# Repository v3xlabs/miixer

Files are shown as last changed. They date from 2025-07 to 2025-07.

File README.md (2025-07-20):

<p align="center">
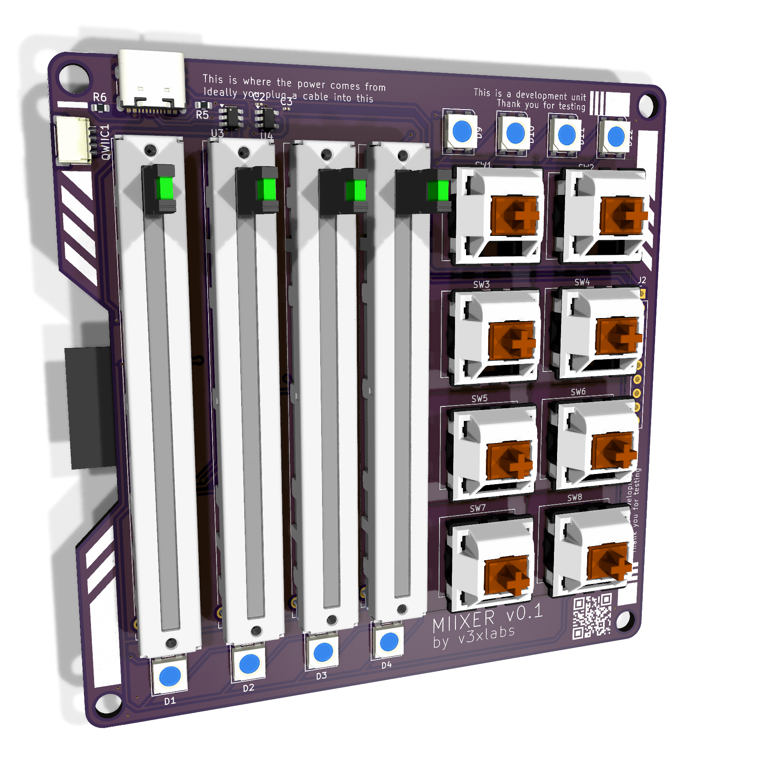
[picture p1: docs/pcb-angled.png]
MIIXER
  
</p>

# MIIXER

An open-hardware midi controller with esp32-c3, 4 linear faders, 8 keyswitches.

> [!NOTE]
> This is a work in progress.

## Technical Specs

- **Processor**: esp32-s3
- **Inputs**
  - 4 linear potentiometers 600mm
  - 8 Cherry MX Switches
- **ICs**
  - [PCF8574T](https://jlcpcb.com/api/file/downloadByFileSystemAccessId/8624297452529963008) - I2C IO Expander
  - [ADS1115IDGS](https://jlcpcb.com/api/file/downloadByFileSystemAccessId/8624297452529963008) - I2C ADC Expander
  - [AP2127K-3.3](https://www.diodes.com/assets/Datasheets/AP2127.pdf) - 5v to 3.3v LDO
  - [USBLC6-2SC6](https://www.st.com/resource/en/datasheet/usblc6-2.pdf) - ESD Protection
- **Connectivity**:
  - USB-C (Power, Data & Flash)
  - Wifi & BLE

## Photos

See the [docs](docs) folder for the rendered schematics, PCBs, and 3D renders.

<p align="center">
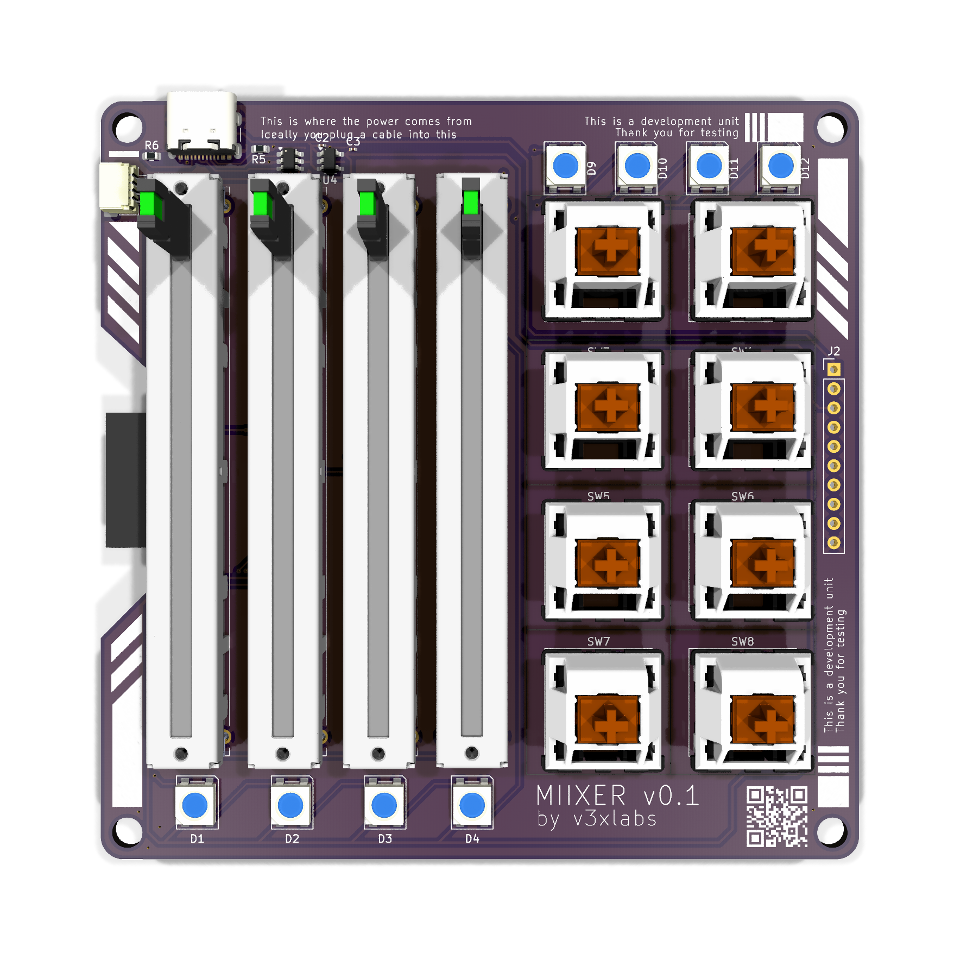
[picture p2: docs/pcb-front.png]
Front of MIIXER
  
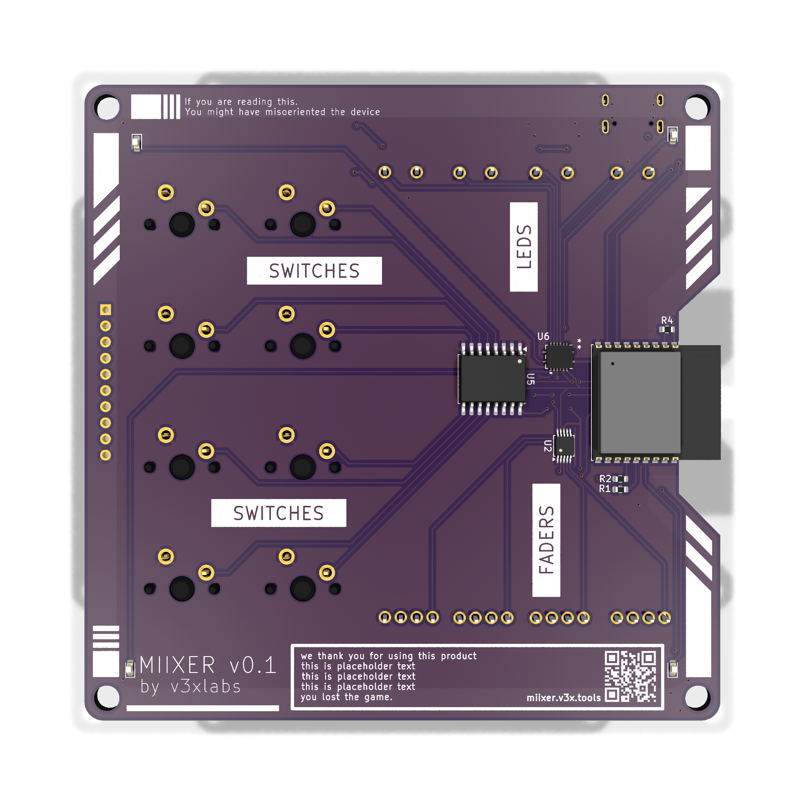
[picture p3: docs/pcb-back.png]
Back of MIIXER
  
</p>

## ESPHome Compatability

Due to the fact that this devices uses common off-the-shelf I2C ICs and is esp32-c3 based, you can easily use it with ESPHome.

```yaml
# TODO: This yaml file is work in progress, its ment to give an impression, its has not been confirmed functional.
i2c:
  sda: GPIO8
  scl: GPIO9
  scan: true

# 4x Fader Input
ads1115:
  address: 0x48 # todo confirm
  update_interval: 5s
  # todo interrupt pin (io6)

# 4x Fader LEDs
tcl59208f:
  id: led_drv # optional
  address: # todo

# 8x Keyswitch Input
pcf8574:
  id: expander # optional
  address: 0x20 # todo confirm
  # todo interrupt pin (io7)

binary_sensor:
  # 8x Keyswitch Input
  - platform: pcf8574
    pin: P0
    name: "Switch 1"
    # todo add 7 more pins

sensor:
  # 4x Fader Analog Input
  - platform: ads1115
    multiplexer: 'A0_GND' # todo
    gain: 6.144 # todo
    # todo 3 more pins

output:
  # 4x Fader LEDs
  - platform: tcl59208f
    driver: led_drv # optional
    id: led1
    channel: 0
  - platform: tcl59208f
    driver: led_drv # optional
    id: led2
    channel: 1
  - platform: tcl59208f
    driver: led_drv # optional
    id: led3
    channel: 2
  - platform: tcl59208f
    driver: led_drv # optional
    id: led4
    channel: 3

light:
  # 4x Fader SK6812
  - platform: fastled_clockless
    chipset: SK6812
    pin: GPIO3
    num_leds: 4
    rgb_order: GRB
    name: "SK6812 Array"
```

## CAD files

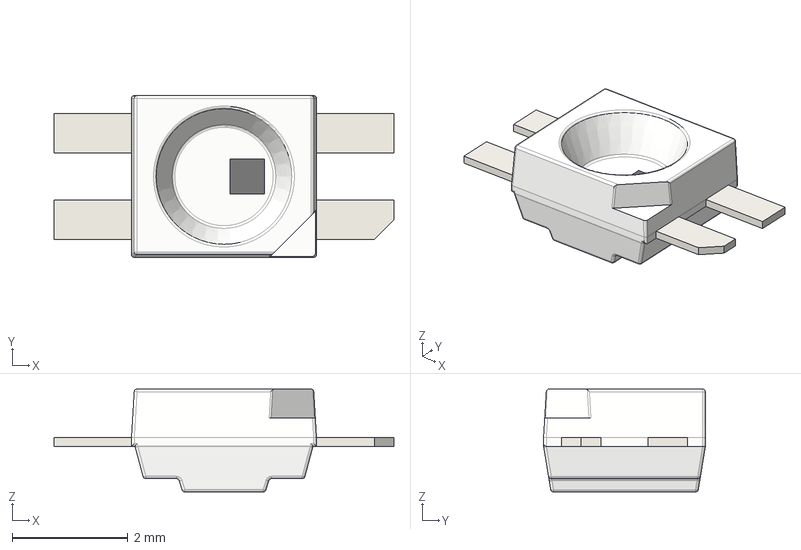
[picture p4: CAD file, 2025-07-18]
footprints/cad_models/sk6812mini-e-1.snapshot.3/LED_SK6812MINI-E.step
5.88 x 2.80 x 1.78 mm

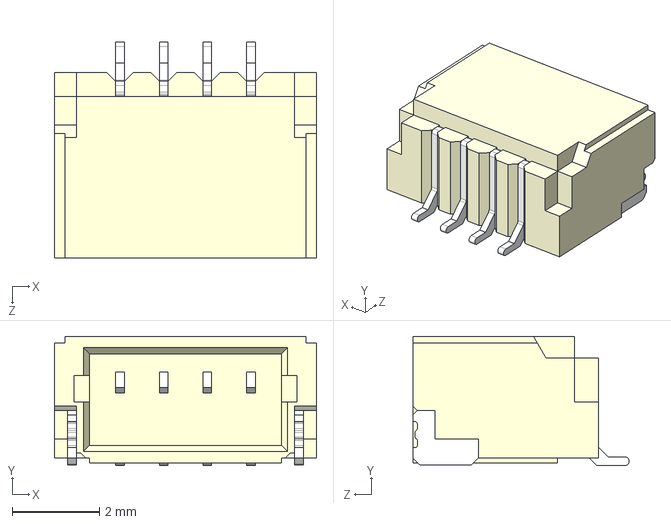
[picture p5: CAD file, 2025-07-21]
footprints/cad_models/SM04B-SRSS-TB.STEP
6.00 x 2.96 x 4.95 mm

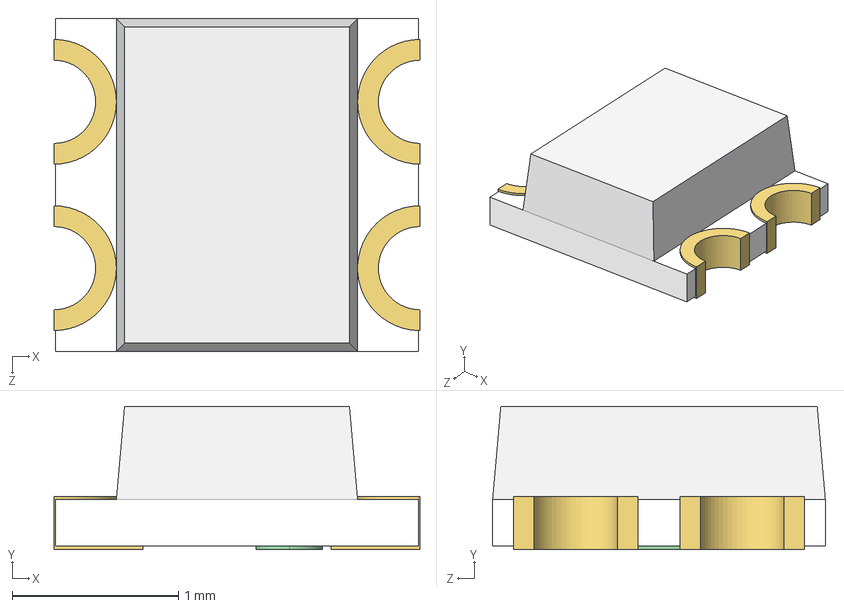
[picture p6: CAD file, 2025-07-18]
footprints/cad_models/ws2812-2020-1.snapshot.4/WS2812-2020.STEP
2.20 x 0.86 x 2.00 mm

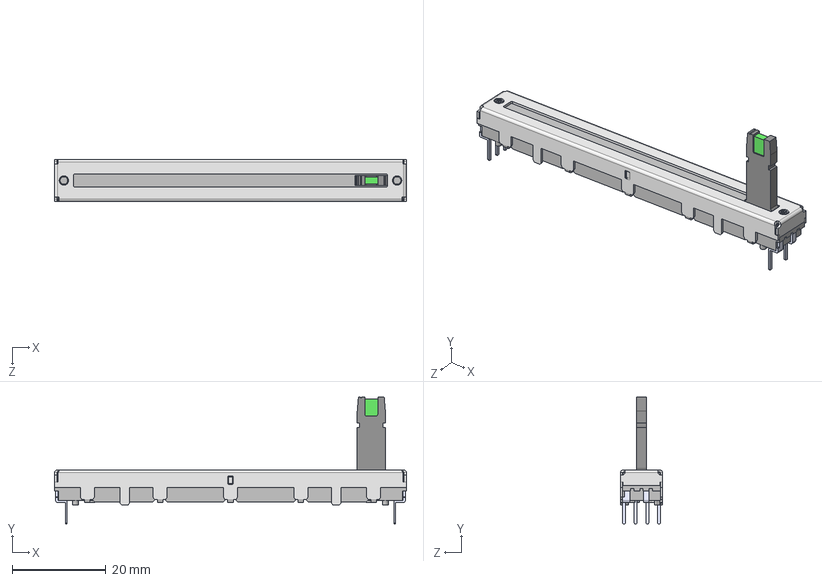
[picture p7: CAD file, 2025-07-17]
footprints/PTL60-15G1-103B2.stp
75.0 x 27.0 x 9.00 mm

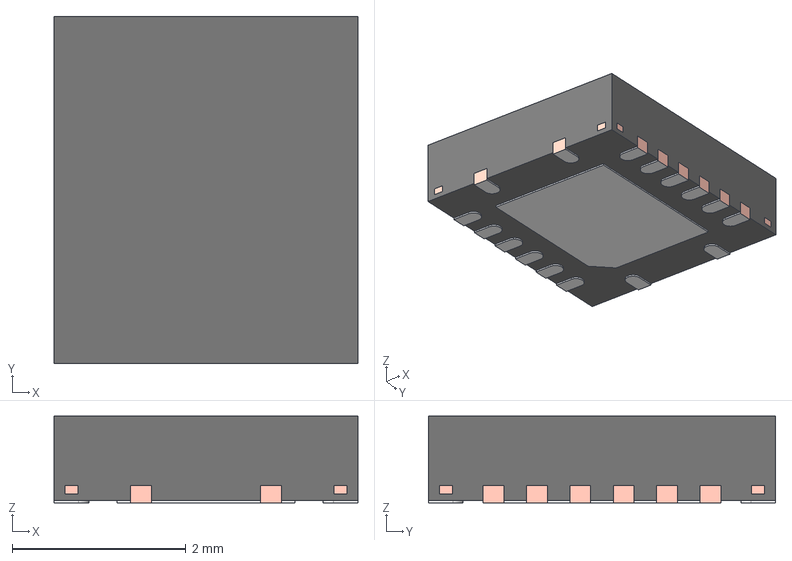
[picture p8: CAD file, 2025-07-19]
footprints/cad_models/RGY0016A.stp
3.50 x 4.00 x 1.00 mm
FRAME
PIN1_AREA

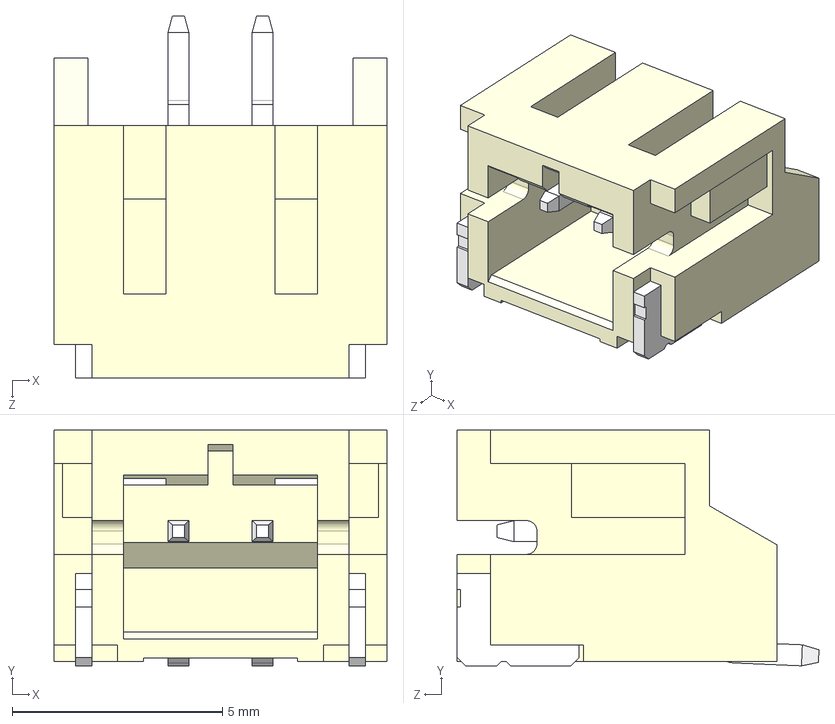
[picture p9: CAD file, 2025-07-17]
footprints/cad_models/S2B-PH-SM4-TB.STEP
7.90 x 5.60 x 8.60 mm

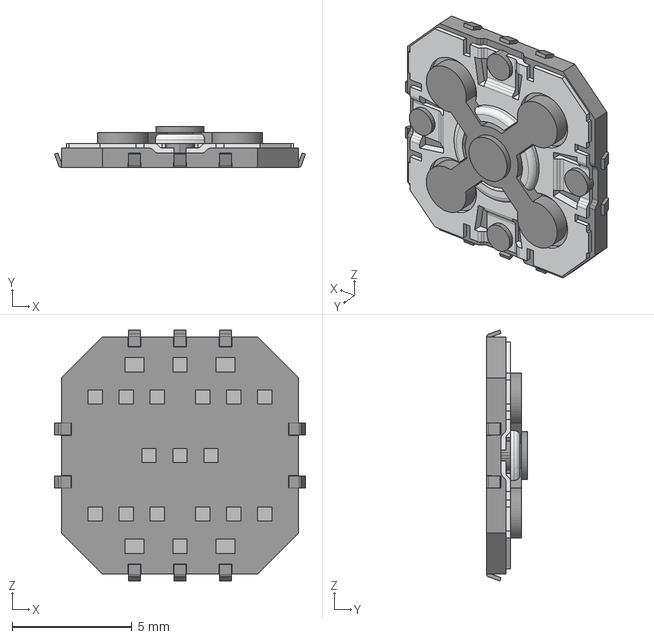
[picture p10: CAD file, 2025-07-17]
footprints/cad_models/btn.step
10.5 x 1.70 x 10.5 mm

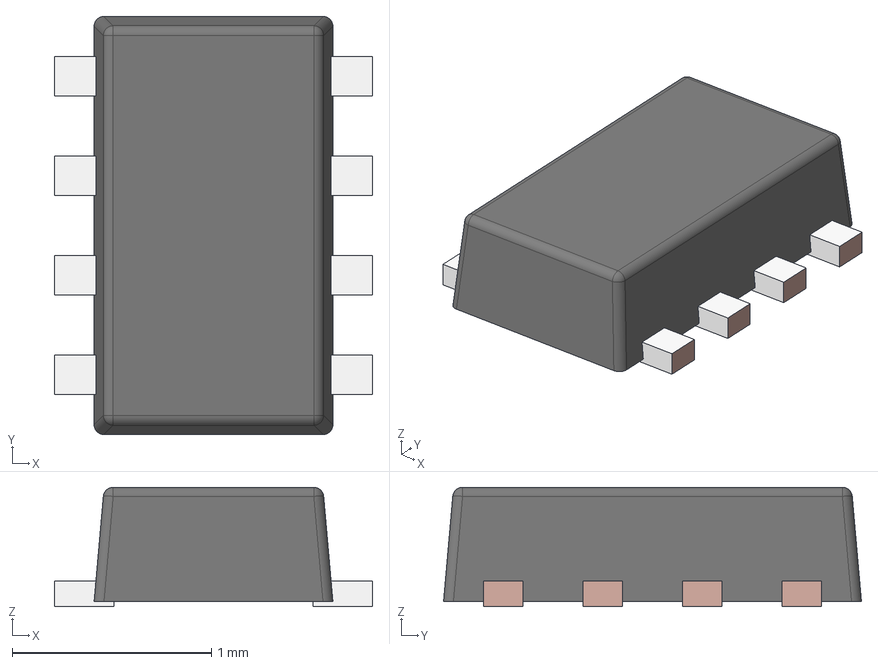
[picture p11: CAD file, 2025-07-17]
footprints/cad_models/DRL0008A.stp
1.60 x 2.10 x 0.6 mm
FRAME-DRL0008A
BODY-SOT

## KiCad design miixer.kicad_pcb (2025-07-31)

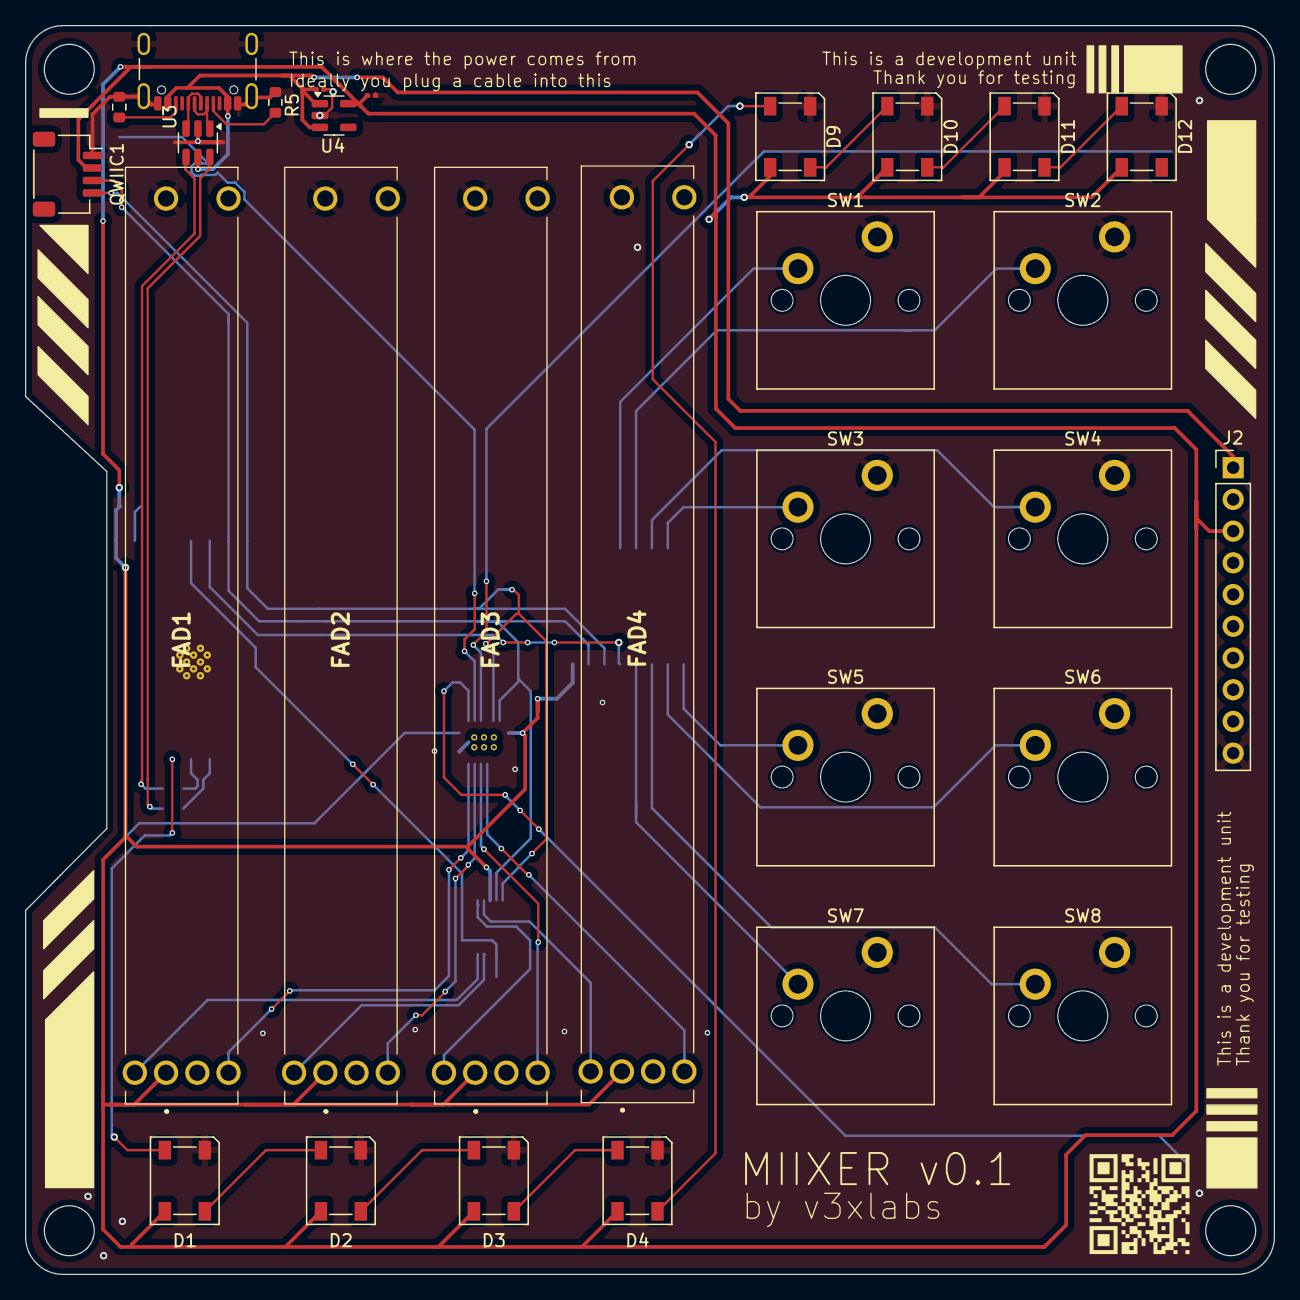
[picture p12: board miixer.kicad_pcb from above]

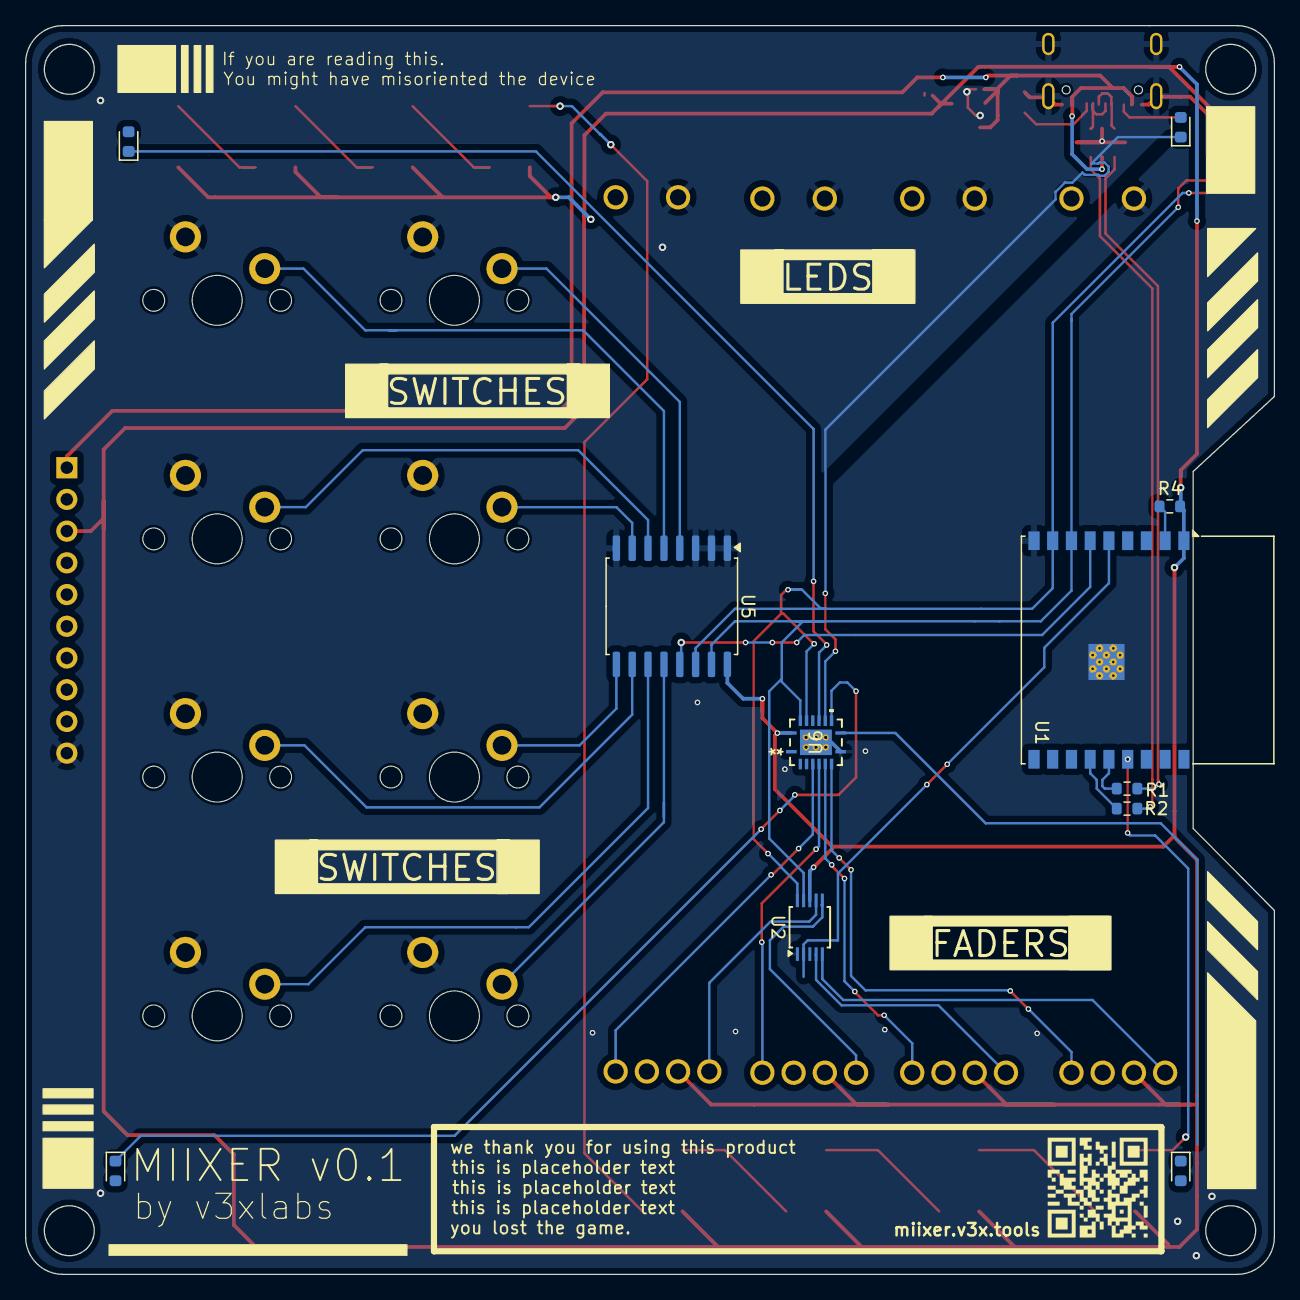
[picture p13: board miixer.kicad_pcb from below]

Board: 2 copper layers, 100.0 x 100.0 mm, 42 parts (12 on the bottom side), 44 nets.

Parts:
C2, C3: C; C_0201_0603Metric
D1, D2, D3, D4, D9, D10, D11, D12: SK6812; LED_SK6812_PLCC4_5.0x5.0mm_P3.2mm
D5, D6, D7, D8: LED; LED_0603_1608Metric
FAD1, FAD2, FAD3, FAD4: PTL60-15G1-103B2; PTL6015G1103B2
J1: TYPE-C 16PIN 2MD(073); USB_C_Receptacle_GCT_USB4105-xx-A_16P_TopMnt_Horizontal
J2: Conn_01x10_Pin; PinHeader_1x10_P2.54mm_Vertical
QR*****: miixer_qrcode_0.35px
QR*****#2: miixer_qrcode_0.35px
QWIIC1: Qwiic; JST_SH_SM04B-SRSS-TB_1x04-1MP_P1.00mm_Horizontal
R1, R2: 22R; R_0603_1608Metric
R4: 10k; R_0603_1608Metric
R5, R6: 5k1; R_0603_1608Metric
SW1, SW2, SW3, SW4, SW5, SW6, SW7, SW8: SW_SPST; SW_Cherry_MX_PCB_1.00u
U1: ESP32-C3-WROOM-02
U2: ADS1115IDGS; TSSOP-10_3x3mm_P0.5mm
U3: USBLC6-2SC6; SOT-23-6
U4: AP2127K-3.3; SOT-23-5
U5: PCF8574T; SOIC-16W_7.5x10.3mm_P1.27mm
U6: TLC59208FIRGYR; RGY16_2P55X2P05

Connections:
+3.3V: C3.1, D1.3 (VDD), D2.3 (VDD), D3.3 (VDD), D4.3 (VDD), D9.3 (VDD), D10.3 (VDD), D11.3 (VDD), D12.3 (VDD), FAD1.1 (CCW), FAD2.1 (CCW), FAD3.1 (CCW), FAD4.1 (CCW), J2.3, QWIIC1.2, R4.2, U1.1 (3V3), U2.8 (VDD), U4.5 (VOUT), U5.16 (VDD), U6.16 (VCC)
/Buttons/ADC_INTERRUPT: U1.5 (IO6), U2.2 (ALERT/RDY)
/Buttons/BTN_INTERRUPT: U1.6 (IO7), U5.13 (~INT)
/Buttons/EXTRA_LED_1: D5.1 (K), U6.12 (*OUT7)
/Buttons/EXTRA_LED_2: D6.1 (K), U6.10 (*OUT5)
/Buttons/EXTRA_LED_3: D7.1 (K), U6.11 (*OUT6)
/Buttons/EXTRA_LED_4: D8.1 (K), U6.9 (*OUT4)
/Buttons/FAD1_LED: FAD1.E1 (E_(-)), U6.7 (*OUT3)
/Buttons/FAD1_WIPER: FAD1.2 (WIPER), U2.5 (AIN1)
/Buttons/FAD2_LED: FAD2.E1 (E_(-)), U6.6 (*OUT2)
/Buttons/FAD2_WIPER: FAD2.2 (WIPER), U2.4 (AIN0)
/Buttons/FAD3_LED: FAD3.E1 (E_(-)), U6.5 (*OUT1)
/Buttons/FAD3_WIPER: FAD3.2 (WIPER), U2.6 (AIN2)
/Buttons/FAD4_LED: FAD4.E1 (E_(-)), U6.4 (*OUT0)
/Buttons/FAD4_WIPER: FAD4.2 (WIPER), U2.7 (AIN3)
/Buttons/LED_MCU: D1.2 (DIN), U1.15 (IO3)
/MCU/ENABLE: R4.1, U1.2 (EN)
/MCU/USBD+: R1.1, U1.14 (IO19)
/MCU/USBD-: R2.1, U1.13 (IO18)
/MCU/USB_D+: R1.2, U3.4 (I/O2)
/MCU/USB_D-: R2.2, U3.6 (I/O1)
/SCL: QWIIC1.4, U1.8 (IO9), U2.10 (SCL), U5.14 (SCL), U6.14 (SCL)
/SDA: QWIIC1.3, U1.7 (IO8), U2.9 (SDA), U5.15 (SDA), U6.15 (SDA)
/USB/CC1: J1.A5 (CC1), R5.1
/USB/CC2: J1.B5 (CC2), R6.1
/USB/USB_RAW_D+: J1.A6 (D+), J1.B6 (D+), U3.3 (I/O2)
/USB/USB_RAW_D-: J1.A7 (D-), J1.B7 (D-), U3.1 (I/O1)
GND: C2.2, C3.2, D1.1 (VSS), D2.1 (VSS), D3.1 (VSS), D4.1 (VSS), D9.1 (VSS), D10.1 (VSS), D11.1 (VSS), D12.1 (VSS), FAD1.3 (CW), FAD2.3 (CW), FAD3.3 (CW), FAD4.3 (CW), J1.A1 (GND), J1.A12 (GND), J1.B1 (GND), J1.B12 (GND), J1.S1 (SHIELD), J2.10, QWIIC1.1, R5.2, R6.2, SW1.2 (B), SW2.2 (B), SW3.2 (B), SW4.2 (B), SW5.2 (B), SW6.2 (B), SW7.2 (B), SW8.2 (B), U1.9 (GND), U1.19 (GND), U2.1 (ADDR), U2.3 (GND), U3.2 (GND), U4.2 (GND), U5.1 (A0), U5.2 (A1), U5.3 (A2), U5.8 (GND), U6.8 (GND), U6.17 (EPAD)
unnamed: D1.4 (DOUT), D2.2 (DIN)
unnamed: D2.4 (DOUT), D3.2 (DIN)
unnamed: D3.4 (DOUT), D4.2 (DIN)
unnamed: D4.4 (DOUT), D9.2 (DIN)
unnamed: D9.4 (DOUT), D10.2 (DIN)
unnamed: D10.4 (DOUT), D11.2 (DIN)
unnamed: D11.4 (DOUT), D12.2 (DIN)
unnamed: SW1.1 (A), U5.4 (P0)
unnamed: SW2.1 (A), U5.5 (P1)
unnamed: SW3.1 (A), U5.7 (P3)
unnamed: SW4.1 (A), U5.6 (P2)
unnamed: SW5.1 (A), U5.9 (P4)
unnamed: SW6.1 (A), U5.10 (P5)
unnamed: SW7.1 (A), U5.12 (P7)
unnamed: SW8.1 (A), U5.11 (P6)
VBUS: C2.1, J1.A4 (VBUS), J1.A9 (VBUS), J1.B4 (VBUS), J1.B9 (VBUS), J2.1, U3.5 (VBUS), U4.1 (VIN), U4.3 (EN)

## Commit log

2025-07-17 Introduce basic kicad project
    [DRL0008A.stp, S2B-PH-SM4-TB.STEP, btn.step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]
2025-07-18 Introduce buttons and update pcb layout
    [buttons.kicad_sch, miixer.kicad_pcb]
2025-07-18 Make square
    [buttons.kicad_sch, mcu.kicad_sch, miixer.kicad_pcb]
2025-07-18 Add keys for each fader & update layout
    [buttons.kicad_sch, miixer.kicad_pcb]
2025-07-18 Reorg layout and remove fader keys
    [buttons.kicad_sch, miixer.kicad_pcb]
2025-07-18 Update image gen
    [miixer.kicad_pcb]
2025-07-18 Added LEDs and improved decals
    [LED_SK6812MINI-E.step, WS2812-2020.STEP, buttons.kicad_sch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]
2025-07-18 Update mcu location
    [miixer.kicad_pcb]
2025-07-18 Update pcb
    [buttons.kicad_sch, miixer.kicad_pcb]
2025-07-18 Update colors
    [miixer.kicad_pcb, miixer.kicad_sch, power.kicad_sch]
2025-07-18 Update power traces
    [buttons.kicad_sch, miixer.kicad_pcb, miixer.kicad_sch]
2025-07-18 Wire buttons
    [buttons.kicad_sch, mcu.kicad_sch, miixer.kicad_pcb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]
2025-07-18 Update bom
    [mcu.kicad_sch, miixer.kicad_pcb, miixer.kicad_sch]
2025-07-19 Add LED driver ic TLC59208F
    [PTL60-15G1-103B2.stp, RGY0016A.stp, buttons.kicad_sch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]
2025-07-21 Add QWIIC connector
    [SM04B-SRSS-TB.STEP, miixer.kicad_pcb, miixer.kicad_sch]
2025-07-21 Update QWIIC connector
    [miixer.kicad_pcb, miixer.kicad_sch]
2025-07-24 Fix layout, rewiring, and clearances
    [buttons.kicad_sch, mcu.kicad_sch, miixer.kicad_pcb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]
2025-07-24 Update layout & ground vias
    [miixer.kicad_pcb]
2025-07-31 Update routing
    [buttons.kicad_sch, miixer.kicad_pcb]
